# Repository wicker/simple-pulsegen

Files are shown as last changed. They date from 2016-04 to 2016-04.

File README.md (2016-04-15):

## Super Simple Function Generator

#### Waveform Generator IC

First off, I want to use a waveform generator IC. It seems like oscillators, audio waveform generators, and pulse generators are all limited kinds of waveform generator ICs. They all seem to cost less than the $10 chip I ended up with.

As far as full waveform generators go, the ICL8038 had an output frequency of up to 300kHz, and the derived MAX038 had an output frequency of up to 20MHz. Both chips are out of stock and no longer manufactured, so they're not an option for this project. 

I'm going to explore PLLs later on but for now I just want a chip that Just Works because the important thing is to generate my own signals. I could use the AD9833 or AD5930, both of which use direct digital synthesis (DDS) that converts a digital signal into an analog waveform.  

It's a tossup between AD9833 and AD5930. They both have 10 bit resolution and run on the same input range between 2.3V to 5.5V. 

AD9833 depends on 25MHz clock and is immediately available in quantity 1 for $9.27 at Digikey. 

AD5930 depends on a 50MHz clock and is not immediately available, and in any case it costs $13.40. And lo, another engineering decision decides itself. 

#### Using the AD9833 

It will produce sine, triangular, and square waves. No external components needed, except that it needs a microcontroller. The analog and digital grounds will need to be separated. It can create sine waves up to 12.5MHz. 

I don't understand how to build the chip itself, so I'm just going to put this on a breakout board and use it.

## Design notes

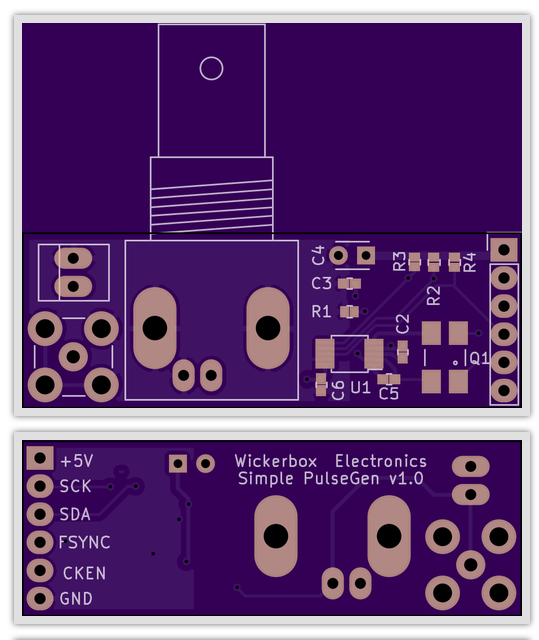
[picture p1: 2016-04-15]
simple-function-generator-v1-osh-preview.png

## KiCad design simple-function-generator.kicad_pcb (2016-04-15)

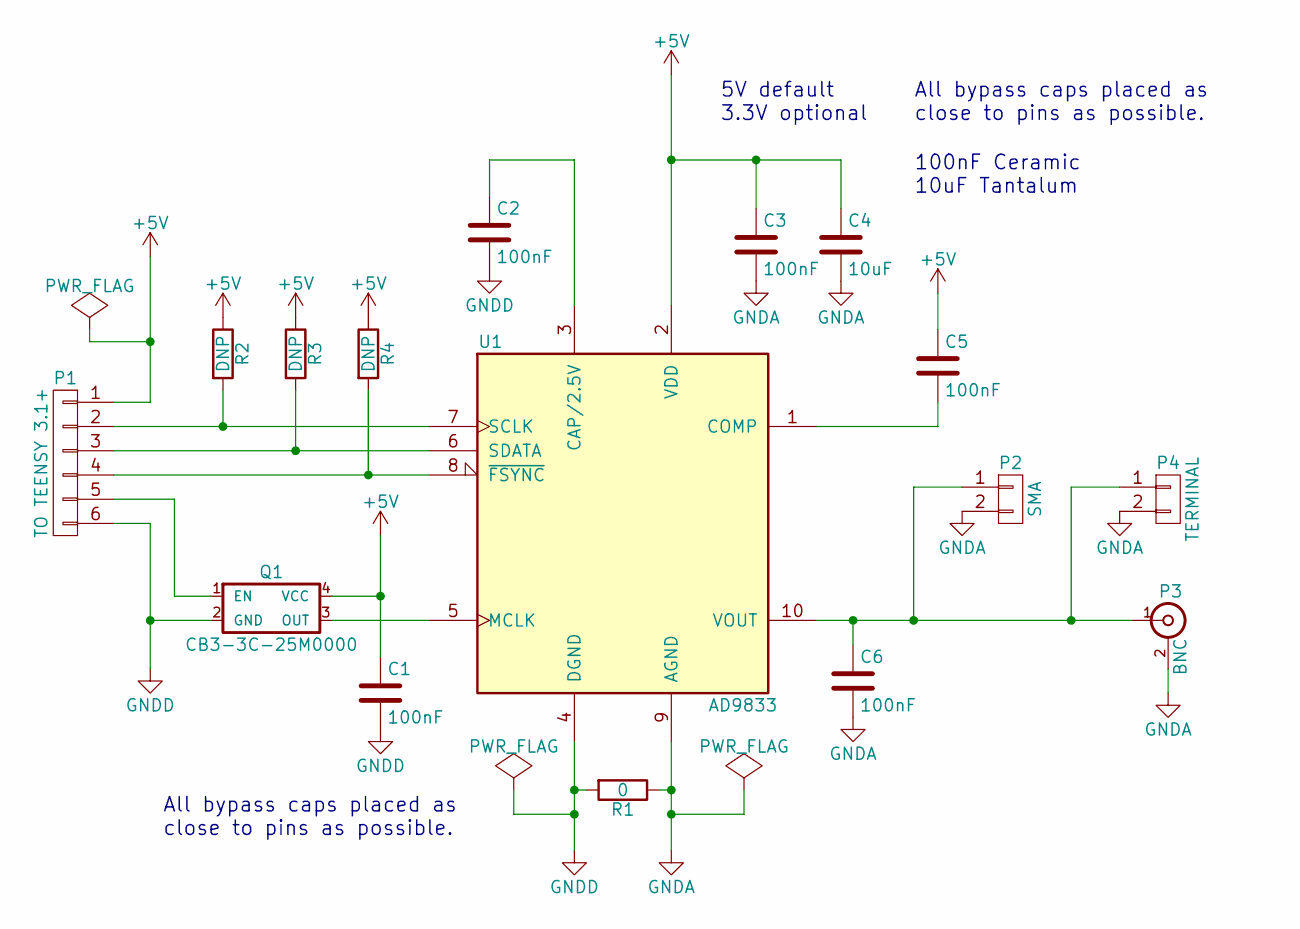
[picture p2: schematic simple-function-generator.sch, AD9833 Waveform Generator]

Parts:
C1, C2, C3, C5, C6: 100nF; C_0402
C4: 10uF; C_Disc_D3_P2.5
P1: TO TEENSY 3.1+; Pin_Header_Straight_1x06
P2: SMA; SMB_Straight
P3: BNC; BNC_Socket_TYCO-AMP_LargePads
P4: TERMINAL; PINHEAD1-2
Q1: CB3-3C-25M0000; Crystal_SMD_0603_4Pads
R1: 0; R_0402
R2, R3, R4: DNP; R_0402
U1: AD9833; MSOP-10_3x3mm_Pitch0.5mm

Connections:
+5V: C1.1, C3.1, C4.1, C5.1, P1.1, Q1.4 (VCC), R2.1, R3.1, R4.1, U1.2 (VDD)
GNDA: C3.2, C4.2, C6.2, P2.2, P3.2 (Ext), P4.2, R1.1, U1.9 (AGND)
GNDD: C1.2, C2.2, P1.6, Q1.2 (GND), R1.2, U1.4 (DGND)
unnamed: C2.1, U1.3 (CAP/2.5V)
unnamed: C5.2, U1.1 (COMP)
unnamed: C6.1, P2.1, P3.1 (In), P4.1, U1.10 (VOUT)
unnamed: P1.2, R2.2, U1.7 (SCLK)
unnamed: P1.3, R3.2, U1.6 (SDATA)
unnamed: P1.4, R4.2, U1.8 (~FSYNC)
unnamed: P1.5, Q1.1 (EN)
unnamed: Q1.3 (OUT), U1.5 (MCLK)

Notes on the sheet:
5V default 3.3V optional
100nF Ceramic 10uF Tantalum
All bypass caps placed as close to pins as possible.

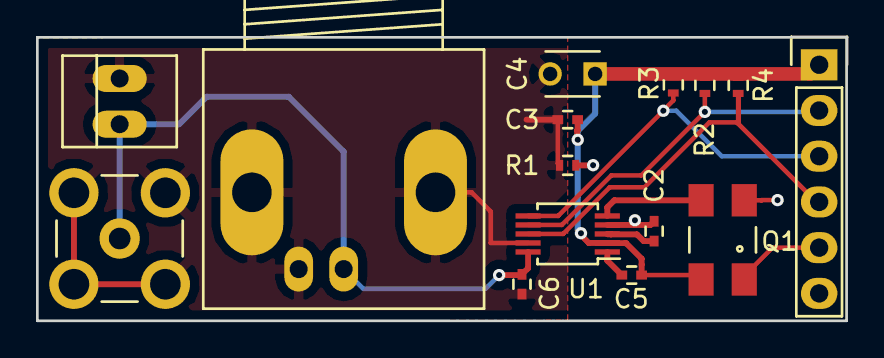
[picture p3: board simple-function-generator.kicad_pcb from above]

Board: 2 copper layers, 45.0 x 15.7 mm, 15 parts (0 on the bottom side), 11 nets.

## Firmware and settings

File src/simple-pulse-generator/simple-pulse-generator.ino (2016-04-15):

  // AD9833 Waveform Generator
  // Jenner Hanni
  // Wickerbox Electronics


  #include "DDS.h"
#include <SPI.h>

void setup()
{
 pinMode( DDS_FSYNC, OUTPUT );
 digitalWrite( DDS_FSYNC, HIGH );
 Serial.begin(19200);
 SPI.setDataMode( SPI_MODE2 );
 SPI.setClockDivider( SPI_CLOCK_DIV2 );
 SPI.setDataMode( MSBFIRST );
 SPI.begin();
 set_timer1_clock();
 delay( 100 );
 Serial.println( "Set timer1" );
 dds_init();
 Serial.println( "DDS Init" );
 dds_set_frequency(1000);
 Serial.println( "DDS Set frequency" );
}

void loop()
{
 
}

void set_timer1_clock()
{
 // Disable timer1
 TCCR1B = 0;
 
 TCCR1A = _BV(COM1A0);
 OCR1A = 7;
 // Start Timer in CTC mode
 TCCR1B = _BV(WGM12) | 1;
}

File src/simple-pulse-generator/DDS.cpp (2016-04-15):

#include <Arduino.h>
#include <SPI.h>
#include "DDS.h"

uint16_t control_reg_value = 0;
uint16_t waveform_mode = DDS_SINE;

void dds_write(uint16_t con)
{
 //SPI.setDataMode( SPI_MODE3 );
 digitalWrite( DDS_FSYNC, LOW );
 delay( 10 );
 SPI.transfer( highByte(con) );
 SPI.transfer( lowByte(con) );
 digitalWrite( DDS_FSYNC, HIGH );
 
 //SPI.setDataMode( SPI_MODE0 );
}

void dds_init()
{
 // Set DDS chip into reset.
 dds_write( _BV(DDS_RESET) );
 
 dds_disable_reset();
}

// Frequency is in 100 mHz increments.
void dds_set_frequency(uint32_t freq)
{
 Serial.println( freq );
 int32_t freq_setting = map_frequency(freq );
 Serial.println( freq_setting );
 dds_write( _BV(DDS_B28) | _BV(DDS_RESET) | waveform_mode );
 // Write frequecy LSBs
 dds_write( (int16_t)(0x4000 | (freq_setting&0x3FFF)) );
 // Write frequency MSBs
 dds_write( (int16_t)(0x4000 | ((freq_setting>>14)&0x3FFF)) );
 
 // Write phase register.
 dds_write( 0b1100000000000000 );

 dds_disable_reset();
}

void dds_set_reset()
{
 dds_write( _BV(DDS_B28) | _BV(DDS_RESET) | waveform_mode );
}

void dds_disable_reset()
{
 dds_write( _BV(DDS_B28) | waveform_mode );
}

void dds_set_waveform_mode(uint16_t mode)
{
 waveform_mode = mode;
 dds_write( _BV(DDS_B28) | waveform_mode );
}

uint64_t map_frequency( uint64_t frequency)
{
 return frequency * DDS_F_SETTING_MAX / DDS_MCLK;
}

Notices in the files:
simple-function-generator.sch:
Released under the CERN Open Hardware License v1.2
